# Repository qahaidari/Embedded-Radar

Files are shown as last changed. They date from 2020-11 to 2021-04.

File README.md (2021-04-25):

# Embedded-Radar-STMicrocontroller-Cprogramming
Embedded radar sensor circuit with STM32 microcontroller and C programming for measuring target speed

# Skills learned in this project:
* GIT
* Basics of hardware design and PCB layout
* Digital and analog circuits
* Accessing peripheral components
* Interrupts, serial I/O, general purpose I/O, ...
* RTOS, multitasking, synchronization, semaphores
* STM32CubeMx configuration code generator
* Schematic CAD software (KiCAD Eeschema): placing parts, connections in schematic, footprints, annotation, netlist
* PCB CAD software (KiCAD): loading netlist, GND pours, Vias, Gerber and Drill files for production
* Soldering components on PCB
* IDE Atollic TrueSTUDIO (Eclipse)
* C programming
* Configuring switches as external interrupts
* Communication between Interrupt Service Routine (ISR) and queue
* Configuring and using ADC
* Configuring and using timers
* Configuring LEDs
* Interfacing with LCD

# Project Description

## Introduction

RADAR stands for Radio Detection And Ranging and is a detection system that uses radio waves to determine the range, angle, or velocity of objects. It can be used to detect aircraft, ships, spacecraft, guided missiles, motor vehicles, weather formations, and terrain. Radars are now involved in various applications. It was initially used for target detection in military applications but nowadays it is used in tracking of aircrafts and vehicles and also in traffic control and space. In this project we will concentrate on motion and speed detection of objects using Radars.

The basic concept of Radar is sending an electromagnetic signal from a source which is radiating in the space. This signal will hit a moving object and then be reflected back to the source. In our case, the transmitter and receiver are on the same board of the radar device. The reflected signal from the object will be processed in the device and then finally sent to a microcontroller where the speed of the moving object is calculated using the Doppler effect.

The Doppler effect is the change of the frequency of an incident wave on a moving object in its reflected wave. The difference in frequencies is measured through a microcontroller to measure the speed of the moving object using the below formulas:

<a href="https://www.codecogs.com/eqnedit.php?latex=\large&space;\Delta&space;f=\frac{2&space;v}{\lambda}" target="_blank">\large \Delta f=\frac{2 v}{\lambda}</a>

<a href="https://www.codecogs.com/eqnedit.php?latex=\large&space;\lambda=\frac{c}{f_t}" target="_blank">\large \lambda=\frac{c}{f_t}</a>

where <a href="https://www.codecogs.com/eqnedit.php?latex=\inline&space;\large&space;\Delta&space;f" target="_blank">\large \Delta f</a> is the difference between transmitted and received frequencies of the signal, <a href="https://www.codecogs.com/eqnedit.php?latex=\inline&space;\large&space;\lambda" target="_blank">\large \lambda</a> is the wavelength, <a href="https://www.codecogs.com/eqnedit.php?latex=\inline&space;\large&space;f_t" target="_blank">\large f_t</a> is the frequency of the transmitted signal, <a href="https://www.codecogs.com/eqnedit.php?latex=\inline&space;\large&space;c" target="_blank">\large c</a> is the speed of light and <a href="https://www.codecogs.com/eqnedit.php?latex=\inline&space;\large&space;v" target="_blank">\large v</a> is the velocity of the object.

## Hardware Setup

### Circuit Design and Components

In this project, we are using an input source for the signal generation and reception, an amplifier and filter stage, a processing unit, a display, two switches and three LEDs. Below figure shows the block diagram of the project.
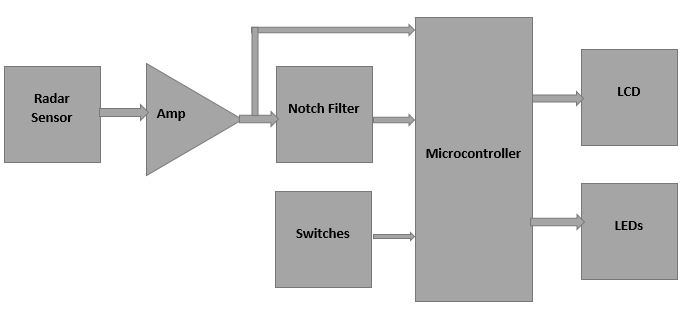
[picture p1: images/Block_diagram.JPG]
Block diagram


In the first stage, we use an IPM-165 Radar module which contains a full duplex patch antenna that transmits and receives signals in the K-band (24GHz). The reflected signal from the moving object has a slightly different frequency than that of the transmitted signal. This difference can be detected by the internal oscillator and the mixer inside the Radar module.

In the next stage, we use an amplifier to amplify the received signal for a more precise measurement and in order to increase the ability to detect objects far from the Radar module.

Due to possible additional noise in the environment which would affect the measurements negatively, we have also included a Notch filter that can suppress the noise at a certain frequency. We have included a filter with a 100Hz frequency suppression as we might have neon light in the environment which would produce signals in this range. The drawback is that the respective speeds in the 100Hz frequency range will not be detected. So we are using both a filtered signal and a non-filtered signal in this project.   

In the next stage we use the STM32L476 microcontroller. It converts the analog signal from the Radar module to a digital signal for processing. By processing the sampled digital signal, the microcontroller calculates the signal frequency and the speed of the object using the Doppler formula. The results for both filtered and non-filtered signals will be displayed on the LCD for user reading.

Two switches (one for switching between the filtered and non-filtered signal and one for freezing the maximum speed on the LCD) and three LEDs (for indicating the filtered, non-filtered and freeze states) are used for user requests and status indication.

### Schematic and Hardware Considerations

There are some points that should be considered in the hardware design in addition to the previous main blocks. We will highlight them in this section as shown in the following schematics.

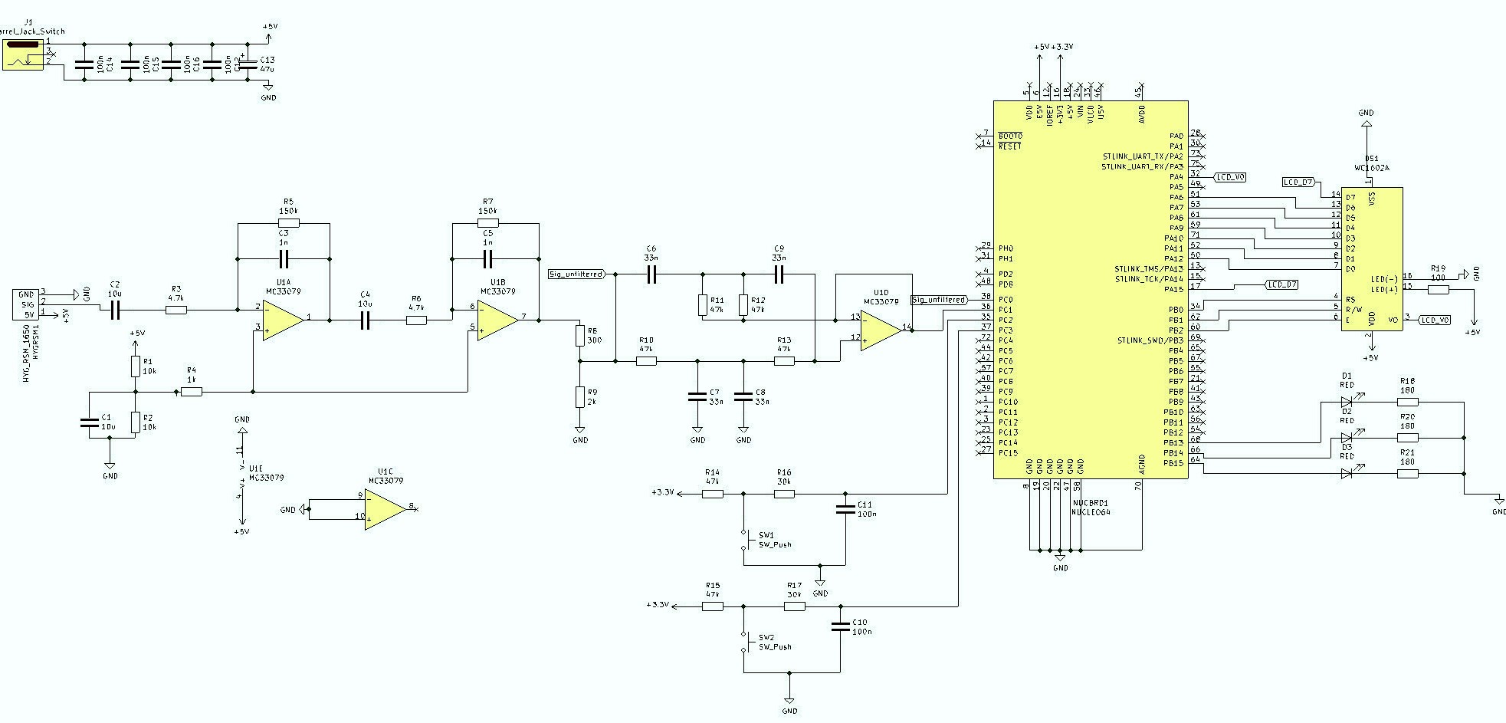
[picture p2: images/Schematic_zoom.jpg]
Schematic zoom


**Power Supply Decoupling Capacitors:** It is highly recommended to connect capacitors to the input DC power supply to minimize the ripples that can be formed due to a non-ideal source. The capacitors C14 to C16 are used at the biasing of operational amplifier, Radar sensor and LCD and the capacitors C12 and C13 are connected to the input power supply. Below figure shows the schematic of decoupling capacitors for main power supply and power supplies of LCD, radar sensor and operational amplifier.

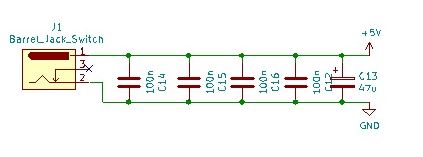
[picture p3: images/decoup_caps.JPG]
Decoup caps


**Operational Amplifier and Notch Filter:** In our design, we used 3 Op-amps, and for size reduction we used a compact IC MC33079 which has 4 Op-amps. The first 2 Op-amps (U1A and U1B) are used in the amplifier circuit stage. The last Op-amp (U1D) is used as a voltage follower to isolate the effect of the load (microcontroller) on the voltage of the connected RC filter at the input of the Op-amp. The Notch filter is used to suppress the effect of noise at 100Hz frequency. Below figure shows the operational amplifier and the Notch filter with their connectivity to the microcontroller. The non-filtered signal is fed to pin PC0 and the filtered signal to pin PC1.

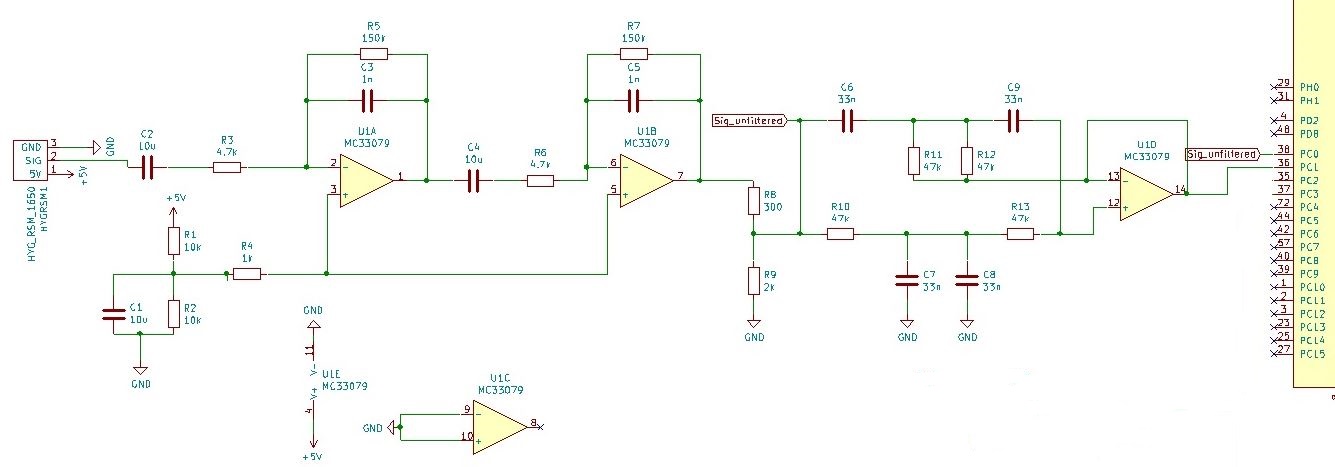
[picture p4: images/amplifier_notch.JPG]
Amplifier notch


**Switch Buttons:** We used 2 switch buttons that should be connected to a debouncing circuit containing resistors and capacitors so that their bouncing when being pressed is canceled. Below figure shows their connectivity with the microcontroller. We used the formula

<a href="https://www.codecogs.com/eqnedit.php?latex=\large&space;U_c(t)&space;=&space;U_0&space;e^{-t/\tau}" target="_blank">\large U_c(t) = U_0 e^{-t/\tau}</a>

to calculate the time <a href="https://www.codecogs.com/eqnedit.php?latex=\inline&space;\large&space;\tau" target="_blank">\large \tau</a>, and from it we can calculate the resistor value <a href="https://www.codecogs.com/eqnedit.php?latex=\inline&space;\large&space;R16=R17=30K\Omega" target="_blank">\large R16=R17=30K\Omega</a> from

<a href="https://www.codecogs.com/eqnedit.php?latex=\large&space;\tau&space;=&space;RC" target="_blank">\large \tau = RC</a>

Taking the bouncing time of the switches as <a href="https://www.codecogs.com/eqnedit.php?latex=\inline&space;\large&space;\textit{t\_bouncing}&space;=&space;0.85&space;\textit{(ms)}" target="_blank">\large \textit{t\_bouncing} = 0.85 \textit{(ms)}</a> and the value of capacitor as <a href="https://www.codecogs.com/eqnedit.php?latex=\inline&space;\large&space;\textit{C}&space;=&space;100&space;\textit{(nF)}" target="_blank">\large \textit{C} = 100 \textit{(nF)}</a>, we calculated  

<a href="https://www.codecogs.com/eqnedit.php?latex=\large&space;\tau&space;>=&space;2.7(ms)" target="_blank">\large \tau >= 2.7(ms)</a>

and this gave us

<a href="https://www.codecogs.com/eqnedit.php?latex=\large&space;R&space;>=&space;27(k\Omega)" target="_blank">\large R >= 27(k\Omega)</a>

We finally chose the smallest E24 resistor for <a href="https://www.codecogs.com/eqnedit.php?latex=\inline&space;\large&space;\textit{R16}" target="_blank">\large \textit{R16}</a> and <a href="https://www.codecogs.com/eqnedit.php?latex=\inline&space;\large&space;\textit{R17}" target="_blank">\large \textit{R17}</a> as <a href="https://www.codecogs.com/eqnedit.php?latex=\inline&space;\large&space;30(k\Omega)" target="_blank">\large 30(k\Omega)</a>. 

Below figure shows the two switches connected to microcontroller.

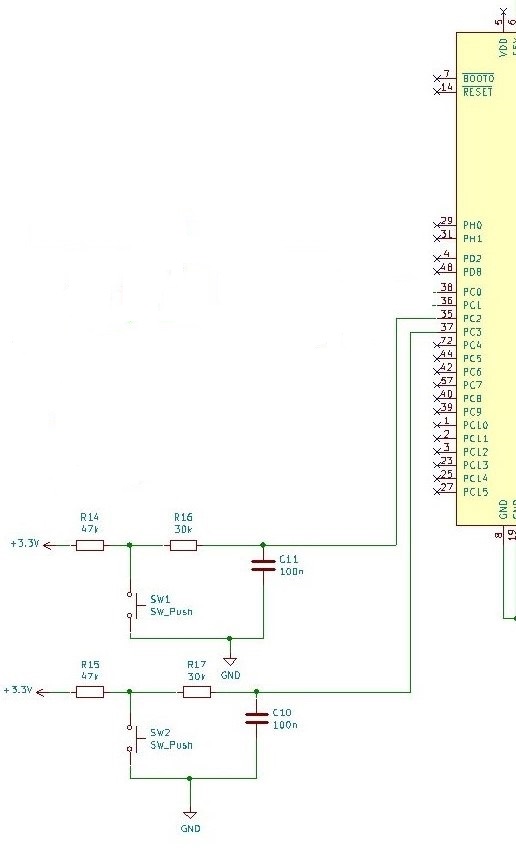
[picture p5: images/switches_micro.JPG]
Switches micor


**LED Indicators:** We used 3 red LEDs for status indication of the measuring process. We need a resistor at each LED to operate them at the desired intensity. According to the data sheet, the voltage drop was calculated using the Kirchoff's voltage law, and the resistors were calculated as <a href="https://www.codecogs.com/eqnedit.php?latex=\inline&space;\large&space;R18=R20=R21=180\Omega" target="_blank">\large R18=R20=R21=180\Omega</a>.

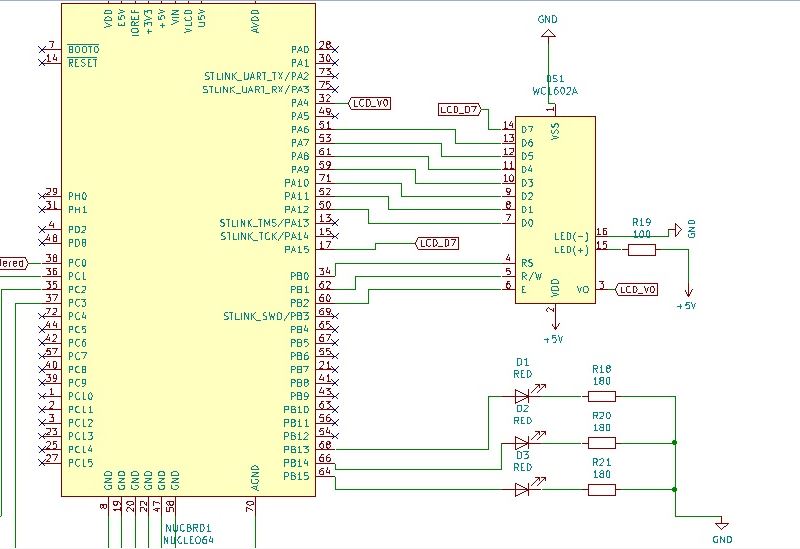
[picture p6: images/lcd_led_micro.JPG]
Lcd led micro


### Operational Flowchart
 
Below figure represents the flowchart of the Radar operation.

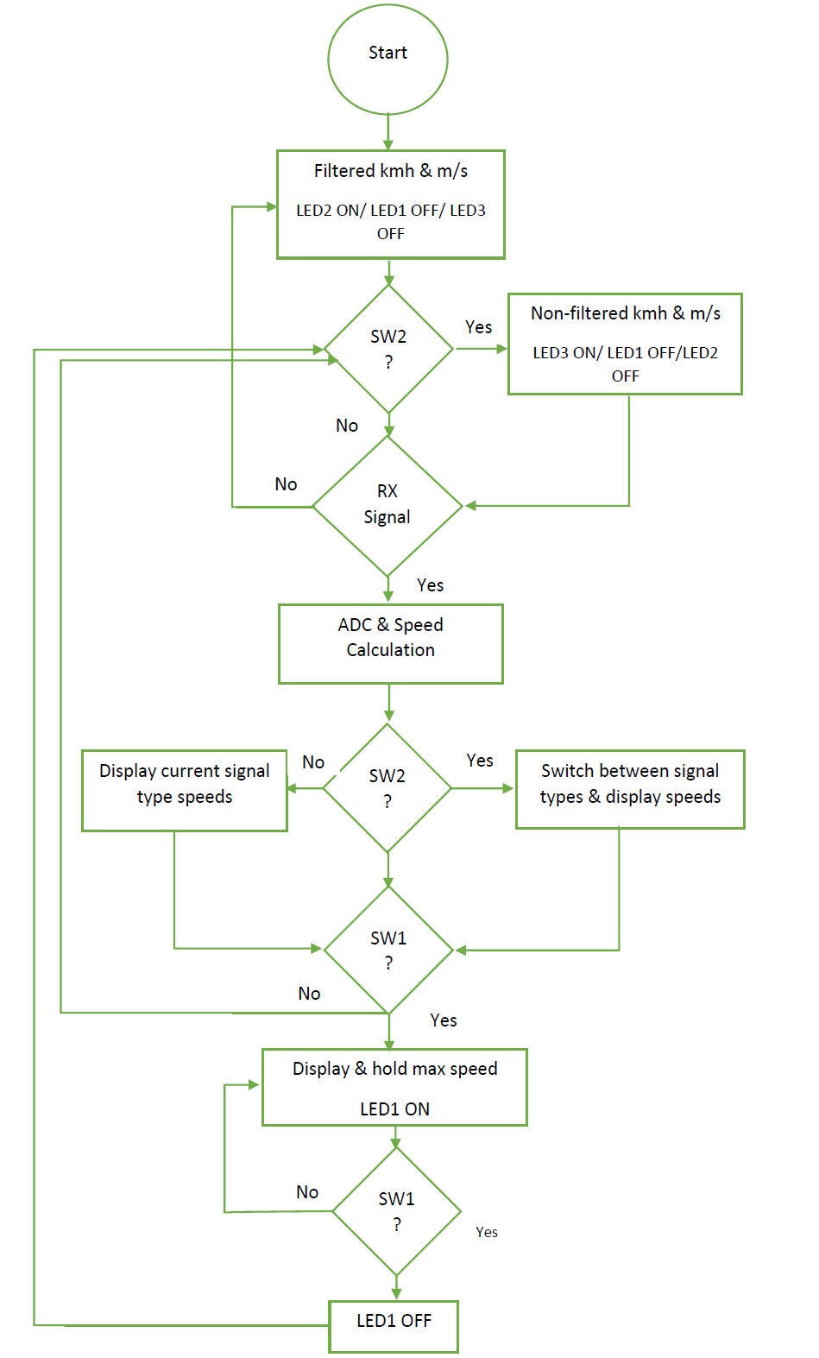
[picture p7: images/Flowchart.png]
Flowchart

 
In this project we have considered 2 scales for the calculation of speed: Kilometer per hour and meter per second, both are displayed on the screen. We can distinguish between filtered and non-filtered signals. The user can switch between them by using switch 2 and the respective speeds in kmh and m/s will be displayed on the LCD. Switch 1 is used to freeze the maximum speed which has been captured so far. LED1 will be ON to indicate the freeze state, and LED2 and LED3 will be ON to show if the filtered signal or the nonfiltered signal has been selected respectively.
 
## Software Concept

**Interrupts:** There are two switches (SW1 and SW2) which act as external interrupts. The following external interrupt callback function sends a specific flag to the queue depending on which one has been pressed.

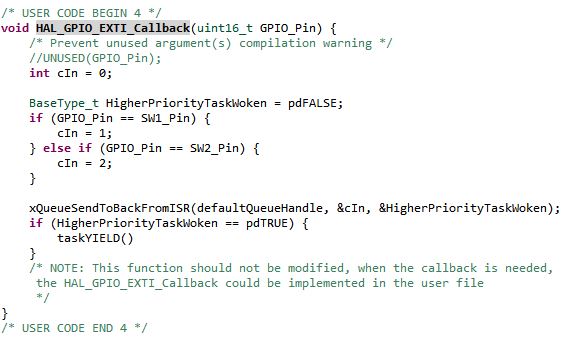
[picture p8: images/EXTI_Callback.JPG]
EXTI callback


In the main task, anytime the SW2 flag is received from the queue, a switch between measurements for filtered and non-filtered signal will happen. This is done by changing the value of a local variable `state` on each SW2-ISR to Task communication. Depending on the value of `state`, an appropriate channel of ADC which takes samples from either a filtered or a non-filtered signal is selected.

**Global Variables:** The following global variables with their respective initial values have been used in the program:

```c 
int final_count = 0;
```
`final_count` indicates number of samples between two successive zeros in the signal.

```c
int timer_div = 0;
```
```c
int sample = 0, prevsample = 0;
```
```c
sample_count = 0;
```
`sample_count` is incremented each time a new sample is taken.

```c
freeze = 1;
```
```c
double min_final_count = 30000;
```

**Timer Settings for ADC Sampling:** The timer parameters have been set as the following:

```c
Prescaler = 1500;
```
```c
Period = 1;
```
```c
ClockDivision = 4;
```
Since the internal clock for the timer is 80MHz, these settings will make the final timer clock around 13333Hz. During each timer clock, ADC takes a sample and converts it to a digital value. This makes the sampling rate over 20 times the highest frequency (600Hz) in the received signal (Nyquist criterion for sampling an analog signal with at least twice the highest frequency in the signal has been fulfilled).

**Local Variables in the Default Task:**
```c
int cIn = 0;
```
```c
int state = 1;
```
```c
double half_period = 0, doppler_f = 0;
```
```c
double v_kmh = 0, v_ms = 0;
```
```c
char str[10];
```

**Static Local Variable:** The static local variable `OFFSET` is used in the timer service routine function to account for the offset value of the received signal.

**Communication between Timer Service Routine Function and the Task:**

Sending the flag `cIn = 3` from the timer SR to the queue: It is sent to the queue whenever a new zero crossing is detected and the current value of `sample_count` is put into `final_count` indicating the number of samples for the previous half period of the signal. `sample_count` value is then set to zero to start counting the number of samples in a new zero-crossing to zero-crossing interval.

The flag `cIn = 4` is sent to the queue whenever the global variable `timer_div` reaches 4000. `timer_div` is incremented any time a timer clock calls the timer service routine function in which a new sample is taken and counted. This flag is used in order not to refresh the contents on the LCD screen any time a new speed is about to be displayed.

**Functions of Switches and LEDs:**

SW2: Switching between filtered and non-filtered measurements

SW1: Freezing the max speed captured so far on LCD. The default state is not to freeze

LED2: Filtered signal has been selected

LED3: Non-filtered signal has been selected

LED1: Indicating the freeze state

**Freezing the Max Speed on LCD:** The global variable `min_final_count = 30000` is used in combination with the global variable `freeze` to freeze the maximum speed which has been captured so far. Switching between freezing and non-freezing states is done by the flag `cIn = 1` which is received in the default task from the EXTI Callback function.

Anytime a switch between filtered and non-filtered signal happens (through SW2), `min_final_count` is reset to 30000 so that the max speed for the new signal type will not be affected by the values of the last signal type. Also, if this switch happens in the freeze state, the speed values will be reset to zero so that the previous frozen max speeds will not stay on the LCD screen.

In the non-freeze state, whenever a new `final_count` is received (through timer SR to task communication), it is compared with the current `min_final_count` to update it for the max speed in the freeze state. In the freeze state, `min_final_count` is taken for measurements.

## Conclusion

**A Concluding Note on Frequency Calculation:** When a signal is received from the Radar sensor, the calculation will be performed in the processor of the microcontroller. Since the highest signal frequency that is received is 600Hz, the sampling rate according to the Nyquist criteria should be at least double this value. We have adjusted the timer parameters in such a way so that the timer service function is called 13333 times per second and within each call, ADC takes one sample. This makes the sampling rate over 20 times the highest frequency. Whenever one sample is taken, it is compared with its previous sample to detect two successive zero crossings and count the number of samples taken within these zero crossings. Since the time for taking one sample is known based on the sampling rate of the timer/ADC, the half period of the signal can be measured. During this process, an offset value and also a threshold value for canceling the noise have been considered. By knowing the period and frequency of the signal, the speed of the object will be measured using the Doppler formula. 

The user can hold the reading on the LCD screen if switch 1 is pressed which will display the maximum speed calculated since the last reading. LED1 will be on to indicate the hold state. The user can release the hold state by pressing switch 1 again and the system will return again to wait for a new received signal.

# Below figure shows the final PCB with soldered components, mounted on the STMicrocontroller.
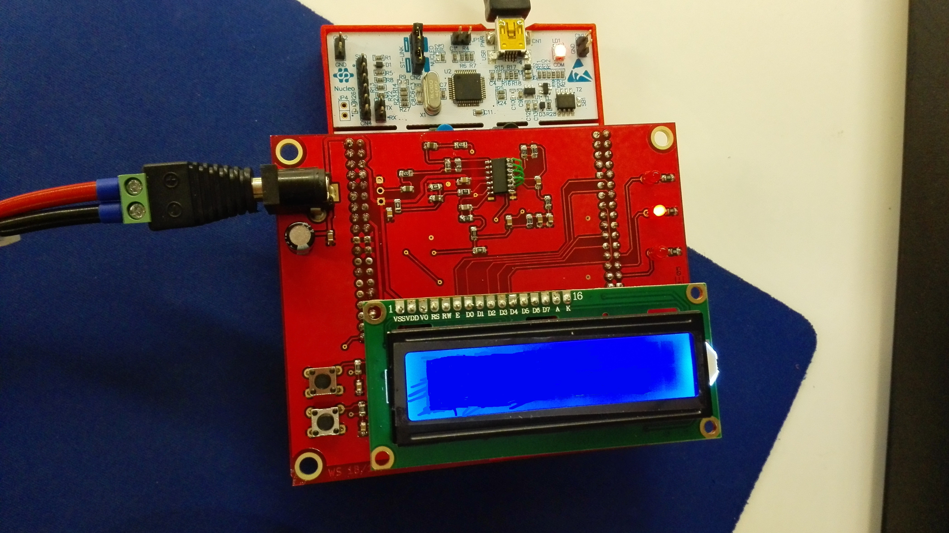
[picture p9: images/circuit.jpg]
circuit


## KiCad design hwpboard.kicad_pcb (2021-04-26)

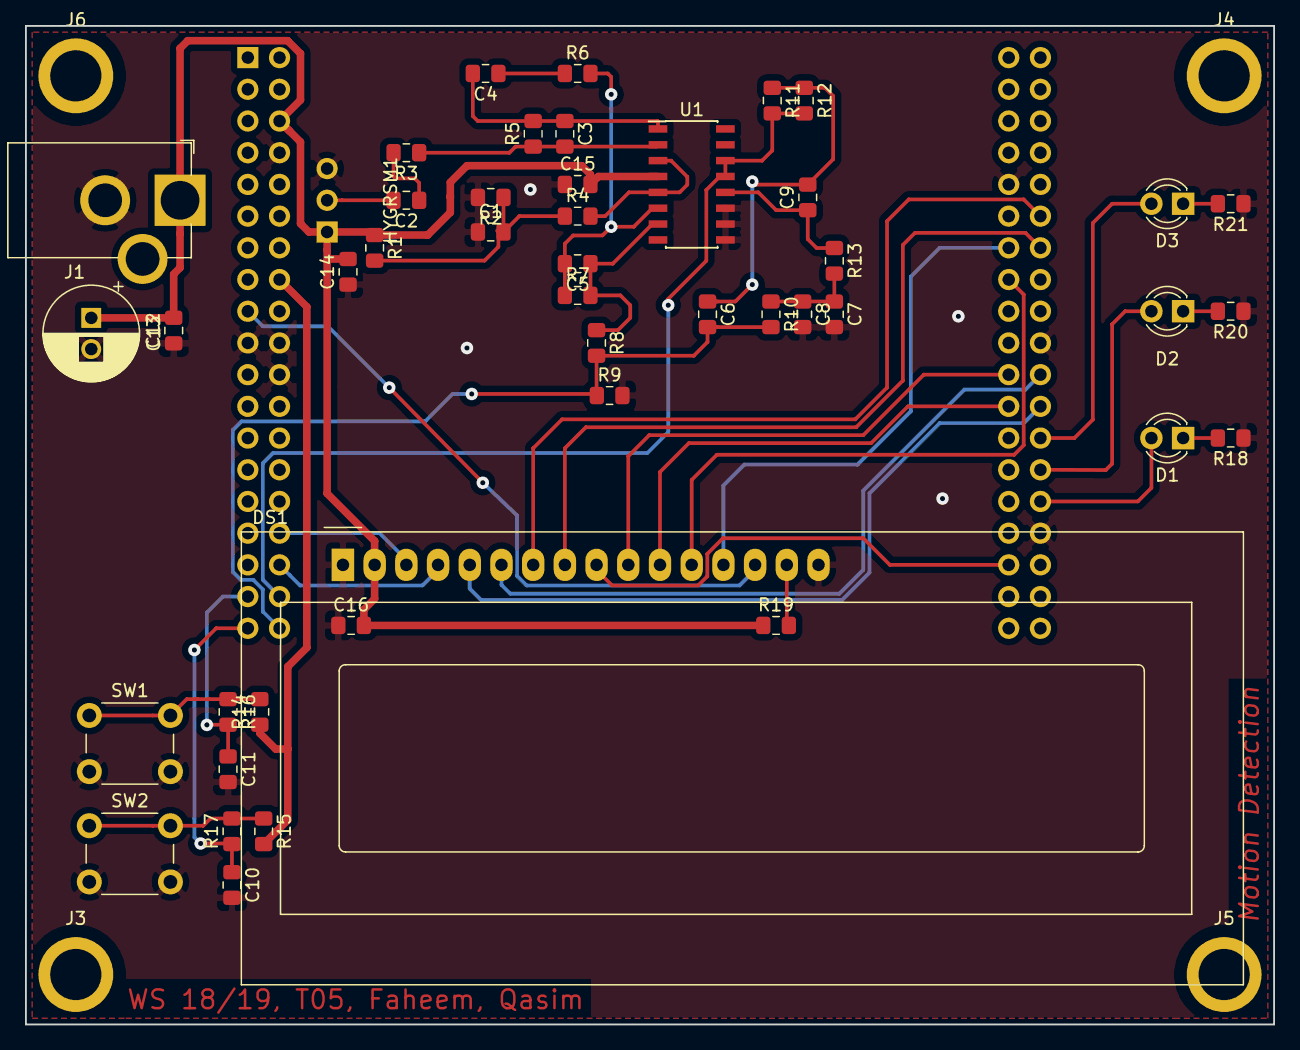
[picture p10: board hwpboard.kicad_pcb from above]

Board: 2 copper layers, 100.0 x 80.0 mm, 51 parts (0 on the bottom side), 40 nets.

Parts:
C1, C2, C4: 10u; C_0805_2012Metric_Pad1.15x1.40mm_HandSolder
C3, C5: 1n; C_0805_2012Metric_Pad1.15x1.40mm_HandSolder
C6, C7, C8, C9: 33n; C_0805_2012Metric_Pad1.15x1.40mm_HandSolder
C10, C11, C12, C14, C15, C16: 100n; C_0805_2012Metric_Pad1.15x1.40mm_HandSolder
C13: 47u; CP_Radial_D7.5mm_P2.50mm
D1, D2, D3: RED; LED_D3.0mm
DS1: WC1602A; WC1602A_no_mount
HYGRSM1: HYG_RSM_1650; HYG_RSM-1650
J1: Barrel_Jack_Switch; BarrelJack_Horizontal_CustomHWP
J3, J4, J5, J6: Conn_01x01; MountingHole_4.1mm_M4_ISO14580_Pad
NUCBRD1: NUCLEO64; ST_Morpho_Connector_STLink
R1, R2: 10k; R_0805_2012Metric_Pad1.15x1.40mm_HandSolder
R3, R6: 4.7k; R_0805_2012Metric_Pad1.15x1.40mm_HandSolder
R4: 1k; R_0805_2012Metric_Pad1.15x1.40mm_HandSolder
R5, R7: 150k; R_0805_2012Metric_Pad1.15x1.40mm_HandSolder
R8: 300; R_0805_2012Metric_Pad1.15x1.40mm_HandSolder
R9: 2k; R_0805_2012Metric_Pad1.15x1.40mm_HandSolder
R10, R11, R12, R13, R14, R15: 47k; R_0805_2012Metric_Pad1.15x1.40mm_HandSolder
R16, R17: 30k; R_0805_2012Metric_Pad1.15x1.40mm_HandSolder
R18, R20, R21: 180; R_0805_2012Metric_Pad1.15x1.40mm_HandSolder
R19: 100; R_0805_2012Metric_Pad1.15x1.40mm_HandSolder
SW1, SW2: SW_Push; SW_PUSH_6mm
U1: MC33079; SOIC-16_3.9x9.9mm_P1.27mm

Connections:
+3V3: NUCBRD1.16, R14.1, R15.2
+5V: C12.2, C13.1, C14.2, C15.2, C16.2, DS1.2, HYGRSM1.1, J1.1, NUCBRD1.6, R1.1, R19.1, U1.4
GND: C1.1, C7.2, C8.2, C10.2, C11.2, C12.1, C13.2, C14.1, C15.1, C16.1, DS1.1, DS1.16, HYGRSM1.3, J1.2, NUCBRD1.8, NUCBRD1.19, NUCBRD1.20, NUCBRD1.22, NUCBRD1.47, NUCBRD1.58, NUCBRD1.70, R2.2, R9.2, R18.1, R20.1, R21.1, SW1.2, SW2.2, U1.9, U1.10, U1.11
LCD_D7: DS1.14, NUCBRD1.17
LCD_V0: DS1.3, NUCBRD1.32
unnamed: C1.2, R1.2, R2.1, R4.1
unnamed: C2.1, R3.2
unnamed: C2.2, HYGRSM1.2
unnamed: C3.1, C4.2, R5.2, U1.1
unnamed: C3.2, R3.1, R5.1, U1.2
unnamed: C4.1, R6.1
unnamed: C5.1, R7.2, R8.1, U1.7
unnamed: C5.2, R6.2, R7.1, U1.6
unnamed: C6.1, C9.2, R11.1, R12.1
unnamed: C7.1, C8.1, R10.1, R13.2
unnamed: C9.1, R13.1, U1.12
unnamed: C10.1, NUCBRD1.37, R17.1
unnamed: C11.1, NUCBRD1.35, R16.2
unnamed: D1.1, R18.2
unnamed: D1.2, NUCBRD1.68
unnamed: D2.1, R20.2
unnamed: D2.2, NUCBRD1.66
unnamed: D3.1, R21.2
unnamed: D3.2, NUCBRD1.64
unnamed: DS1.4, NUCBRD1.34
unnamed: DS1.5, NUCBRD1.62
unnamed: DS1.6, NUCBRD1.60
unnamed: DS1.7, NUCBRD1.50
unnamed: DS1.8, NUCBRD1.52
unnamed: DS1.9, NUCBRD1.71
unnamed: DS1.10, NUCBRD1.59
unnamed: DS1.11, NUCBRD1.61
unnamed: DS1.12, NUCBRD1.53
unnamed: DS1.13, NUCBRD1.51
unnamed: DS1.15, R19.2
unnamed: NUCBRD1.36, R11.2, R12.2, U1.13, U1.14
unnamed: R4.2, U1.3, U1.5
unnamed: R14.2, R16.1, SW1.1
unnamed: R15.1, R17.2, SW2.1
Sig_unfiltered: C6.2, NUCBRD1.38, R8.2, R9.1, R10.2

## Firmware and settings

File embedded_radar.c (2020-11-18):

/**
 ******************************************************************************
 * @file           : main.c
 * @brief          : Main program body
 ******************************************************************************
 * This notice applies to any and all portions of this file
 * that are not between comment pairs USER CODE BEGIN and
 * USER CODE END. Other portions of this file, whether
 * inserted by the user or by software development tools
 * are owned by their respective copyright owners.
 *
 * Copyright (c) 2019 STMicroelectronics International N.V.
 * All rights reserved.
 *
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
 ******************************************************************************
 */
/* Includes ------------------------------------------------------------------*/
#include "main.h"
#include "stm32l4xx_hal.h"
#include "cmsis_os.h"

/* USER CODE BEGIN Includes */
#include <stdbool.h>
#include <stdio.h>
#include "defines.h"
#include "tm_stm32_hd44780.h"
/* USER CODE END Includes */

ADC_HandleTypeDef hadc1;

DAC_HandleTypeDef hdac1;

TIM_HandleTypeDef htim2;

UART_HandleTypeDef huart2;
DMA_HandleTypeDef hdma_usart2_tx;

osThreadId defaultTaskHandle;
uint32_t defaultTaskBuffer[512];
osStaticThreadDef_t defaultTaskControlBlock;
osThreadId auxTaskHandle;
uint32_t auxTaskFxnBuffer[512];
osStaticThreadDef_t auxTaskFxnControlBlock;
osMessageQId defaultQueueHandle;
uint8_t defaultQueueBuffer[4 * sizeof(uint16_t)];
osStaticMessageQDef_t defaultQueueControlBlock;
osMessageQId auxQueueHandle;
uint8_t auxQueueBuffer[4 * sizeof(uint16_t)];
osStaticMessageQDef_t auxQueueControlBlock;
osTimerId timer01Handle;
osStaticTimerDef_t timer01ControlBlock;

/* USER CODE BEGIN PV */
int final_count = 0;
int timer_div = 0;
int sample = 0, prevsample = 0, sample_count = 0, freez = 1;
double min_final_count = 30000;

/* USER CODE END PV */

void SystemClock_Config(void);
static void MX_GPIO_Init(void);
static void MX_DMA_Init(void);
static void MX_USART2_UART_Init(void);
static void MX_ADC1_Init(void);
static void MX_DAC1_Init(void);
static void MX_TIM2_Init(void);
void defaultTaskFxn(void const * argument);
void auxTaskFxn(void const * argument);
void timer01Callback(void const * argument);

/* USER CODE BEGIN PFP */

/* USER CODE END PFP */

/**
 * @brief  The application entry point.
 *
 * @retval None
 */
int main(void) {
	/* MCU Configuration----------------------------------------------------------*/

	/* Reset of all peripherals, Initializes the Flash interface and the Systick. */
	HAL_Init();

	/* Configure the system clock */
	SystemClock_Config();

	/* Initialize all configured peripherals */
	MX_GPIO_Init();
	MX_DMA_Init();
	MX_USART2_UART_Init();
	MX_ADC1_Init();
	MX_DAC1_Init();
	MX_TIM2_Init();
	/* USER CODE BEGIN RTOS_MUTEX */
	/* add mutexes, ... */
	/* USER CODE END RTOS_MUTEX */

	/* USER CODE BEGIN RTOS_SEMAPHORES */
	/* add semaphores, ... */
	/* USER CODE END RTOS_SEMAPHORES */

	/* Create the timer(s) */
	/* definition and creation of timer01 */
	osTimerStaticDef(timer01, timer01Callback, &timer01ControlBlock);
	timer01Handle = osTimerCreate(osTimer(timer01), osTimerOnce, NULL);

	/* USER CODE BEGIN RTOS_TIMERS */
	/* start timers, add new ones, ... */
	HAL_TIM_Base_Start_IT(&htim2);
	HAL_TIM_Base_MspInit(&htim2);
	/* USER CODE END RTOS_TIMERS */

	/* Create the thread(s) */
	/* definition and creation of defaultTask */
	osThreadStaticDef(defaultTask, defaultTaskFxn, osPriorityNormal, 0, 512,
			defaultTaskBuffer, &defaultTaskControlBlock);
	defaultTaskHandle = osThreadCreate(osThread(defaultTask), NULL);

	/* definition and creation of auxTask */
	osThreadStaticDef(auxTask, auxTaskFxn, osPriorityNormal, 0, 512,
			auxTaskFxnBuffer, &auxTaskFxnControlBlock);
	auxTaskHandle = osThreadCreate(osThread(auxTask), NULL);

	/* USER CODE BEGIN RTOS_THREADS */
	/* add threads, ... */
	/* USER CODE END RTOS_THREADS */

	/* Create the queue(s) */
	/* definition and creation of defaultQueue */
	osMessageQStaticDef(defaultQueue, 4, uint16_t, defaultQueueBuffer,
			&defaultQueueControlBlock);
	defaultQueueHandle = osMessageCreate(osMessageQ(defaultQueue), NULL);

	/* definition and creation of auxQueue */
	osMessageQStaticDef(auxQueue, 4, uint16_t, auxQueueBuffer,
			&auxQueueControlBlock);
	auxQueueHandle = osMessageCreate(osMessageQ(auxQueue), NULL);

	/* USER CODE BEGIN RTOS_QUEUES */
	/* add queues, ... */
	/* USER CODE END RTOS_QUEUES */

	/* Start scheduler */
	osKernelStart();

	/* We should never get here as control is now taken by the scheduler */

	/* Infinite loop */
	/* USER CODE BEGIN WHILE */
	while (1) {

		/* USER CODE END WHILE */

		/* USER CODE BEGIN 3 */

	}
	/* USER CODE END 3 */

}

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
/* USER CODE BEGIN 4 */
void HAL_GPIO_EXTI_Callback(uint16_t GPIO_Pin) {
	/* Prevent unused argument(s) compilation warning */
	//UNUSED(GPIO_Pin);
	int cIn = 0;

	BaseType_t HigherPriorityTaskWoken = pdFALSE;
	if (GPIO_Pin == SW1_Pin) {
		cIn = 1;
	} else if (GPIO_Pin == SW2_Pin) {
		cIn = 2;
	}

	xQueueSendToBackFromISR(defaultQueueHandle, &cIn, &HigherPriorityTaskWoken);
	if (HigherPriorityTaskWoken == pdTRUE) {
		taskYIELD()
	}
	/* NOTE: This function should not be modified, when the callback is needed,
	 the HAL_GPIO_EXTI_Callback could be implemented in the user file
	 */
}
/* USER CODE END 4 */

/* USER CODE BEGIN Header_defaultTaskFxn */
/**
 * @brief  Function implementing the defaultTask thread.
 * @param  argument: Not used
 * @retval None
 */
/* USER CODE END Header_defaultTaskFxn */
void defaultTaskFxn(void const * argument) {

	/* USER CODE BEGIN 5 */
	int cIn = 0;
	int state = 1;
	double half_period = 0, doppler_f = 0;
	double v_kmh = 0, v_ms = 0;
	char str[10];

	ADC_ChannelConfTypeDef sConfig;
	sConfig.Channel = ADC_CHANNEL_1;
	sConfig.Rank = ADC_REGULAR_RANK_1;
	sConfig.SamplingTime = ADC_SAMPLETIME_12CYCLES_5;
	sConfig.SingleDiff = ADC_SINGLE_ENDED;
	sConfig.OffsetNumber = ADC_OFFSET_NONE;
	sConfig.Offset = 0;

	TM_HD44780_Init(16, 2);
	TM_HD44780_DisplayOn();
	TM_HD44780_Clear();
	HAL_DAC_Start(&hdac1, 1);
	HAL_DAC_SetValue(&hdac1, 1, 12, 500);

	/* Infinite loop */
	for (;;) {
		if (xQueueReceive(defaultQueueHandle, &cIn, 0)) {
			if (cIn == 2) { /* switch between filtered or non-filtered signal */
				if (state == 1)
					state = 2;
				else if (state == 2)
					state = 1;
				min_final_count = 30000;
				if (freez == 2) {
					v_kmh = 0;
					v_ms = 0;
				}
			}

			if (cIn == 3 && freez != 2) { /* take final count from queue */
				if (final_count > 1 && final_count < min_final_count) {
					min_final_count = final_count;
				}
				half_period = (double) final_count * 0.000075;
				doppler_f = 1 / (half_period * 2);
				v_kmh = doppler_f / 44; /* velocity in km/h */
				v_ms = v_kmh * 0.28; /* velocity in m/s */

			}
			if (cIn == 4) {
				//TM_HD44780_Clear();
				if (state == 2) {
					TM_HD44780_Puts(0, 0, "f=  ");
					TM_HD44780_Puts(0, 1, "f=  ");
				} else if (state == 1) {
					TM_HD44780_Puts(0, 0, "Unf=");
					TM_HD44780_Puts(0, 1, "Unf=");
				}
				sprintf(str, "%.2f   ", v_kmh);
				TM_HD44780_Puts(5, 0, str);
				TM_HD44780_Puts(13, 0, "kmh");
				sprintf(str, "%.2f    ", v_ms);
				TM_HD44780_Puts(5, 1, str);
				TM_HD44780_Puts(13, 1, "ms");
			}
			if (cIn == 1) { /* switch 1 is pressed */
				if (freez == 1) {
					freez = 2;
					half_period = (double) min_final_count * 0.000075;
					doppler_f = 1 / (half_period * 2);
					v_kmh = doppler_f / 44; /* velocity in km/h */
					v_ms = v_kmh * 0.28; /* velocity in m/s */
					HAL_GPIO_WritePin(GPIOB, LED1_Pin, GPIO_PIN_SET);
				} else if (freez == 2) {
					freez = 1;
					HAL_GPIO_WritePin(GPIOB, LED1_Pin, GPIO_PIN_RESET);
				}
//					TM_HD44780_Clear();
//					sprintf(str, "%f", v_kmh);
//					TM_HD44780_Puts(10, 0, str);
//					TM_HD44780_Puts(13, 0, "kmh");
//					sprintf(str, "%f", v_ms);
//					TM_HD44780_Puts(10, 1, str);
//					TM_HD44780_Puts(13, 1, "ms");
			}
		}

		if (state == 2) { /* choose filtered signal */
			sConfig.Channel = ADC_CHANNEL_2;
			HAL_GPIO_WritePin(GPIOB, LED3_Pin, GPIO_PIN_RESET);
			HAL_GPIO_WritePin(GPIOB, LED2_Pin, GPIO_PIN_SET);
		} else if (state == 1) { /* choose non-filtered signal */
			sConfig.Channel = ADC_CHANNEL_1;
			HAL_GPIO_WritePin(GPIOB, LED2_Pin, GPIO_PIN_RESET);
			HAL_GPIO_WritePin(GPIOB, LED3_Pin, GPIO_PIN_SET);
		}
		if (HAL_ADC_ConfigChannel(&hadc1, &sConfig) != HAL_OK) {
			_Error_Handler(__FILE__, __LINE__);
		}
	}
	/* USER CODE END 5 */
}

/* USER CODE BEGIN Header_auxTaskFxn */
/**
 * @brief Function implementing the auxTask thread.
 * @param argument: Not used
 * @retval None
 */
/* USER CODE END Header_auxTaskFxn */
void auxTaskFxn(void const * argument) {
	/* USER CODE BEGIN auxTaskFxn */
	/* Infinite loop */
//	/* Infinite loop */
	for (;;) {
		osDelay(100);
	}

	/* USER CODE END auxTaskFxn */
}

/* timer01Callback function */
void timer01Callback(void const * argument) {
}

/**
 * @brief  Period elapsed callback in non blocking mode
 * @note   This function is called  when TIM17 interrupt took place, inside
 * HAL_TIM_IRQHandler(). It makes a direct call to HAL_IncTick() to increment
 * a global variable "uwTick" used as application time base.
 * @param  htim : TIM handle
 * @retval None
 */
void HAL_TIM_PeriodElapsedCallback(TIM_HandleTypeDef *htim) {
	/* USER CODE BEGIN Callback 0 */
	int cIn = 0;
//	char str[10];
	BaseType_t HigherPriorityTaskWoken = pdFALSE;
	if (htim->Instance == TIM2) {
		timer_div++;
		if (!(timer_div % 4000)) {
			timer_div = 0;
			cIn = 4;
			xQueueSendToBackFromISR(defaultQueueHandle, &cIn,
					&HigherPriorityTaskWoken);
			if (HigherPriorityTaskWoken == pdTRUE) {
				taskYIELD()
			}
		}

//		int sample = 0, prevsample = 0, sample_count = 0;
		HAL_ADC_Start(&hadc1);
		HAL_ADC_PollForConversion(&hadc1, 0);
		sample = HAL_ADC_GetValue(&hadc1);
		//	sprintf(str, "%d", sample);
		//	TM_HD44780_Puts(0,0,str);
		HAL_ADC_Stop(&hadc1);

		if ((prevsample < OFFSET - 10 && sample > OFFSET + 10)
				|| (prevsample > OFFSET + 10 && sample < OFFSET - 10)) {
			final_count = sample_count++;
			sample_count = 0;
			cIn = 3;
			xQueueSendToBackFromISR(defaultQueueHandle, &cIn,
					&HigherPriorityTaskWoken);
			if (HigherPriorityTaskWoken == pdTRUE) {
				taskYIELD()
			}
		}
		prevsample = sample;
		sample_count++;
	}
	/* USER CODE END Callback 0 */
	if (htim->Instance == TIM17) {
		HAL_IncTick();
	}
}

/**
 * @brief  This function is executed in case of error occurrence.
 * @param  file: The file name as string.
 * @param  line: The line in file as a number.
 * @retval None
 */
void _Error_Handler(char *file, int line) {
	/* USER CODE BEGIN Error_Handler_Debug */
	/* User can add his own implementation to report the HAL error return state */
	while (1) {
	}
	/* USER CODE END Error_Handler_Debug */
}

#ifdef  USE_FULL_ASSERT
/**
 * @brief  Reports the name of the source file and the source line number
 *         where the assert_param error has occurred.
 * @param  file: pointer to the source file name
 * @param  line: assert_param error line source number
 * @retval None
 */
void assert_failed(uint8_t* file, uint32_t line)
{
	/* USER CODE BEGIN 6 */
	/* User can add his own implementation to report the file name and line number,
	 tex: printf("Wrong parameters value: file %s on line %d\r\n", file, line) */
	/* USER CODE END 6 */
}
#endif /* USE_FULL_ASSERT */

/**
 * @}
 */

/**
 * @}
 */

/************************ (C) COPYRIGHT STMicroelectronics *****END OF FILE****/

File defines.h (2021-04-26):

/**
 * @author  Tilen Majerle
 * @email   tilen@majerle.eu
 * @website http://stm32f4-discovery.net
 * @link    http://stm32f4-discovery.net/2015/07/hal-library-15-hd44780-for-stm32fxxx/
 * @version v1.0
 * @ide     Keil uVision
 * @license MIT
 * @brief   HD44780 LCD driver library for STM32Fxxx
 *	
\verbatim
   ----------------------------------------------------------------------
    Copyright (c) 2016 Tilen Majerle

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
    THE SOFTWARE IS PROVIDED "AS IS", WITHOUT WARRANTY OF ANY KIND,
    EXPRESS OR IMPLIED, INCLUDING BUT NOT LIMITED TO THE WARRANTIES
    OF MERCHANTABILITY, FITNESS FOR A PARTICULAR PURPOSE
    AND NONINFRINGEMENT. IN NO EVENT SHALL THE AUTHORS OR COPYRIGHT
    HOLDERS BE LIABLE FOR ANY CLAIM, DAMAGES OR OTHER LIABILITY,
    WHETHER IN AN ACTION OF CONTRACT, TORT OR OTHERWISE, ARISING 
    FROM, OUT OF OR IN CONNECTION WITH THE SOFTWARE OR THE USE OR
    OTHER DEALINGS IN THE SOFTWARE.
   ----------------------------------------------------------------------
\endverbatim
 */
#ifndef DEFINES_H
#define DEFINES_H 100

/* C++ detection */
#ifdef __cplusplus
extern "C" {
#endif


/* 4 bit mode */
/* Control pins, can be overwritten */
/* RS - Register select pin */
#ifndef HD44780_RS_PIN
#define HD44780_RS_PORT				GPIOB
#define HD44780_RS_PIN				GPIO_PIN_0
#endif
/* E - Enable pin */
#ifndef HD44780_E_PIN
#define HD44780_E_PORT				GPIOB
#define HD44780_E_PIN				GPIO_PIN_2
#endif
/* Data pins */
/* D4 - Data 4 pin */
#ifndef HD44780_D4_PIN
#define HD44780_D4_PORT				GPIOA
#define HD44780_D4_PIN				GPIO_PIN_8
#endif
/* D5 - Data 5 pin */
#ifndef HD44780_D5_PIN
#define HD44780_D5_PORT				GPIOA
#define HD44780_D5_PIN				GPIO_PIN_7
#endif
/* D6 - Data 6 pin */
#ifndef HD44780_D6_PIN
#define HD44780_D6_PORT				GPIOA
#define HD44780_D6_PIN				GPIO_PIN_6
#endif
/* D7 - Data 7 pin */
#ifndef HD44780_D7_PIN
#define HD44780_D7_PORT				GPIOA
#define HD44780_D7_PIN				GPIO_PIN_15
#endif





/* C++ detection */
#ifdef __cplusplus
}
#endif

#endif
